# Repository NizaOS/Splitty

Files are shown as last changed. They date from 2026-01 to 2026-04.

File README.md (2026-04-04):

<header style="text-align: center; margin-bottom: 40px;">
<h1 style="font-size: 3em; margin-bottom: 10px;">SPLITTY</h1>
<p style="font-size: 1.2em; color: #555;">A 40% Wireless Split Mechanical Keyboard</p>
<p><b>Low Profile &bull; Choc v1 &bull; ZMK Firmware &bull; 1000mAh Battery Life</b></p>
<hr>
</header>
<section>
<h2>Project Overview</h2>
<p>SPLITTY is a custom-built, wireless split keyboard designed for portability and ergonomics. It utilizes the <b>Seeed Studio XIAO nRF52840</b> for Bluetooth 5.0 connectivity and is built on a custom PCB optimized for <b>Kailh Choc v1</b> low-profile switches.</p>


<h3>why i made this project</h3>
    <p>i wanted a low profile split keyboard that was actually portable and didnt cost a fortune. most commerical options are too bulky or wired only so i decided to desin something that fits in a laptop bag easily while keeping the ergonomics of a split layout.</p>

<h3>how to use</h3>
    <p>to use the keyboard you need to flash zmk firmware to both halves. double tap reset button on the xiao to enter bootloader mode then drag and drop the uf2 files. once its flashed you can pair it to your computer via bluetooth settings by searching for splitty. the left side is usually the central half that connects to the pc.</p>
    <h3>Technical Specifications</h3>
    <ul>
        <li><b>Microcontroller:</b> 2x Seeed Studio XIAO nRF52840 (Bluetooth 5.0)</li>
        <li><b>Switch Type:</b> Kailh Choc v1 (PG1350) - Linear/Tactile/Clicky</li>
        <li><b>Battery:</b> 2x 1000mAh LiPo (WLY394058) - Approx. 1+ month battery life</li>
        <li><b>PCB Features:</b> Hotswap support, reversible footprint, 1.2mm thickness</li>
        <li><b>Firmware:</b> ZMK (Wireless-first firmware)</li>
    </ul>
</section>
<hr>
<section>
    <h2>Bill of Materials (BOM)</h2>
    <p><i>Prices estimated in USD based on INR conversion ($1 &#8776; &#8377;90.27).</i></p>
            <table border="1" cellpadding="10" cellspacing="0" style="width: 100%; border-collapse: collapse; text-align: left;">
        <thead>
            <tr style="background-color: #f2f2f2;">
                <th>Component</th>
                <th>Qty</th>
                <th>Unit Price</th>
                <th>Total (USD)</th>
                <th>Sourcing Link</th>
            </tr>
        </thead>
        <tbody>
            <tr>
                <td><b>Seeed XIAO BLE nRF52840</b></td>
                <td>2</td>
                <td>$14.88</td>
                <td>$25.87</td>
                <td><a href="[https://www.fabtolab.com/seeed-xiao-ble-nrf52840-supports-arduino-micropython-bluetooth5.0-onboard-antenna-microcontroller-32-bit-arm-cortex-m4](https://www.fabtolab.com/seeed-xiao-ble-nrf52840-supports-arduino-micropython-bluetooth5.0-onboard-antenna-microcontroller-32-bit-arm-cortex-m4)" target="_blank">Fab.to.Lab</a></td>
            </tr>
            <tr>
                <td><b>Kailh Choc v1 Switches</b></td>
                <td>40</td>
                <td>$0.55</td>
                <td>$22.00</td>
                <td><a href="[https://neomacro.in/products/kailh-choc-pg1350-hot-swap-sockets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](https://neomacro.in/products/kailh-choc-pg1350-hot-swap-sockets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)" target="_blank">NeoMacro</a></td>
            </tr>
            <tr>
                <td><b>Choc Hotswap Sockets</b></td>
                <td>40</td>
                <td>$0.18</td>
                <td>$7.00</td>
                <td><a href="[https://neomacro.in/products/kailh-choc-v1-switches](https://neomacro.in/products/kailh-choc-v1-switches)" target="_blank">NeoMacro</a></td>
            </tr>
            <tr>
                <td><b>MBK/MCC Keycaps</b></td>
                <td>40</td>
                <td>$0.40</td>
                <td>$16.00</td>
                <td><a href="[https://neomacro.in/products/chocfox-cfx-choc-blank-keycaps?variant=49467027685654](https://neomacro.in/products/chocfox-cfx-choc-blank-keycaps?variant=49467027685654)" target="_blank">NeoMacro</a></td>
            </tr>
            <tr>
                <td><b>PCB (Manufacturing)</b></td>
                <td>1</td>
                <td>$21.00</td>
                <td>$21.00</td>
                <td><a href="[https://jlcpcb.com/](https://jlcpcb.com/)" target="_blank">JLCPCB</a></td>
            </tr>
            <tr>
                <td><b>3D Printed Case (Shipping)</b></td>
                <td>1</td>
                <td>$10.00</td>
                <td>$10.00</td>
                <td>Printing Legion</td>
            </tr>
            <tr>
                <td><b>LiPo Battery (1000mAh)</b><br><small>Model: WLY394058 (3.9mm thick)</small></td>
                <td>2</td>
                <td>$4.18</td>
                <td>$8.36</td>
                <td><a href="[https://robu.in/product/wly394058-1000mah-3-7v-single-cell-rechargeable-lipo-battery/](https://robu.in/product/wly394058-1000mah-3-7v-single-cell-rechargeable-lipo-battery/)" target="_blank">Robu.in</a></td>
            </tr>
            <tr>
                <td><b>1N4148W Diodes (SOD-123)</b></td>
                <td>40</td>
                <td>$0.006</td>
                <td>$0.24</td>
                <td><a href="[https://robu.in/product/1n4148w-sod-123-1206-diodereel-of-3000/](https://robu.in/product/1n4148w-sod-123-1206-diodereel-of-3000/)" target="_blank">Robu.in</a></td>
            </tr>
            <tr>
                <td><b>806K1 Resistor (0805)</b></td>
                <td>10</td>
                <td>$0.023</td>
                <td>$0.14</td>
                <td><a href="[https://robu.in/product/ac0402fr-07806kl-yageo-62-5mw-thick-film-resistors-50v-](https://robu.in/product/ac0402fr-07806kl-yageo-62-5mw-thick-film-resistors-50v-)±100ppm-℃-±1-806kω-0402-chip-resistor-surface-mount-rohs/" target="_blank">Robu.in</a></td>
            </tr>
            <tr>
                <td><b>2M1 Resistor (0805)</b></td>
                <td>10</td>
                <td>$0.020</td>
                <td>$0.11</td>
                <td><a href="[https://robu.in/product/rc0603fr-0716rl-yageo-smd-chip-resistor-16-ohm-](https://robu.in/product/rc0603fr-0716rl-yageo-smd-chip-resistor-16-ohm-)±-1-100-mw-0603-1608-metric-thick-film-general-purpose/" target="_blank">Robu.in</a></td>
            </tr>
            <tr style="font-weight: bold; background-color: #e6e6e6;">
                <td colspan="3" style="text-align: right;">ESTIMATED TOTAL</td>
                <td colspan="2">$110.72</td>
            </tr>
        </tbody>
    </table>
</section>

<hr>

<div id="gallery" style="padding: 20px; background-color: #f9f9f9; border: 1px solid #ddd; margin-top: 30px;">
    <h2 style="text-align: center;">Project Gallery</h2>
    
  

  



</div>
</div>

</body>
</html>

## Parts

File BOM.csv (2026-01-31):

Item | Quantity | Unit Price | Total Price | Source | Link
Seeed XIAO BLE nRF52840 | 2 | $14.88 | $25.87 | Fab.to.Lab | https://www.fabtolab.com/seeed-xiao-ble-nrf52840-supports-arduino-micropython-bluetooth5.0-onboard-antenna-microcontroller-32-bit-arm-cortex-m4
Kailh Choc v1 Switches | 40 | $0.55 | $22.00 | NeoMacro | https://neomacro.in/products/kailh-choc-pg1350-hot-swap-sockets
Choc Hotswap Sockets | 40 | $0.18 | $7.00 | NeoMacro | https://neomacro.in/products/kailh-choc-v1-switches
MBK/MCC Keycaps | 40 | $0.40 | $16.00 | NeoMacro | https://neomacro.in/products/chocfox-cfx-choc-blank-keycaps?variant=49467027685654
PCB (Manufacturing) | 1 | $21.00 | $21.00 | JLCPCB | https://jlcpcb.com/
3D Printed Case (Shipping) | 1 | $10.00 | $10.00 | Printing Legion | N/A
LiPo Battery (1000mAh) | 2 | $4.18 | $8.36 | Robu.in | https://robu.in/product/wly394058-1000mah-3-7v-single-cell-rechargeable-lipo-battery/
1N4148W Diodes (SOD-123) | 40 | $0.006 | $0.24 | Robu.in | https://robu.in/product/1n4148w-sod-123-1206-diodereel-of-3000/
806K1 Resistor (0805) | 10 | $0.023 | $0.14 | Robu.in | https://robu.in/product/ac0402fr-07806kl-yageo-62-5mw-thick-film-resistors-50v-±100ppm-℃-±1-806kω-0402-chip-resistor-surface-mount-rohs/
2M1 Resistor (0805) | 10 | $0.020 | $0.11 | Robu.in | https://robu.in/product/rc0603fr-0716rl-yageo-smd-chip-resistor-16-ohm-±-1-100-mw-0603-1608-metric-thick-film-general-purpose/
TOTAL |  |  | $110.72

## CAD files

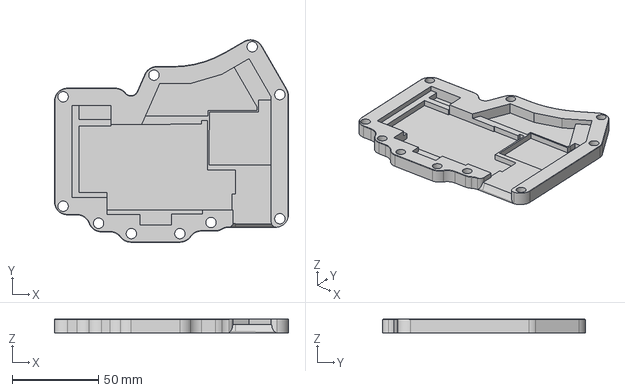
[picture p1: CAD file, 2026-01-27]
SplittyCAD/Right FInal.step
135.4 x 117.2 x 8.04 mm

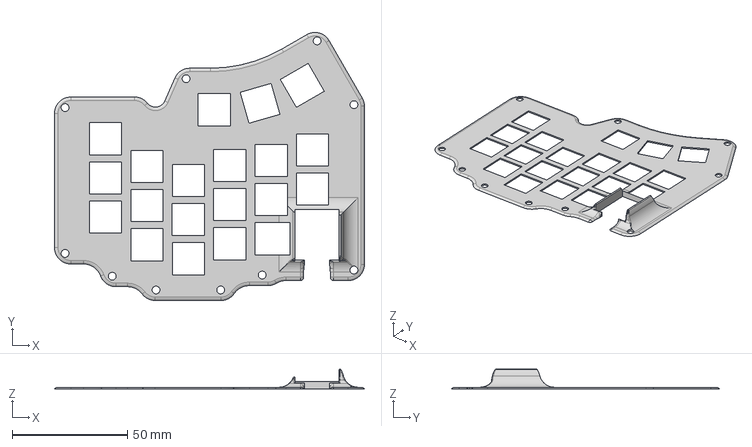
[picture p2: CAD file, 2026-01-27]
SplittyCAD/Upper Right Final.step
134.5 x 116.3 x 8.59 mm

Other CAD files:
SplittyCAD/Left FInal.step
SplittyCAD/Upper Left Final.step
SplittyCAD/Left FInal.stl
SplittyCAD/Right FInal.stl
SplittyCAD/Upper Left Final.stl
SplittyCAD/Upper Right Final.stl

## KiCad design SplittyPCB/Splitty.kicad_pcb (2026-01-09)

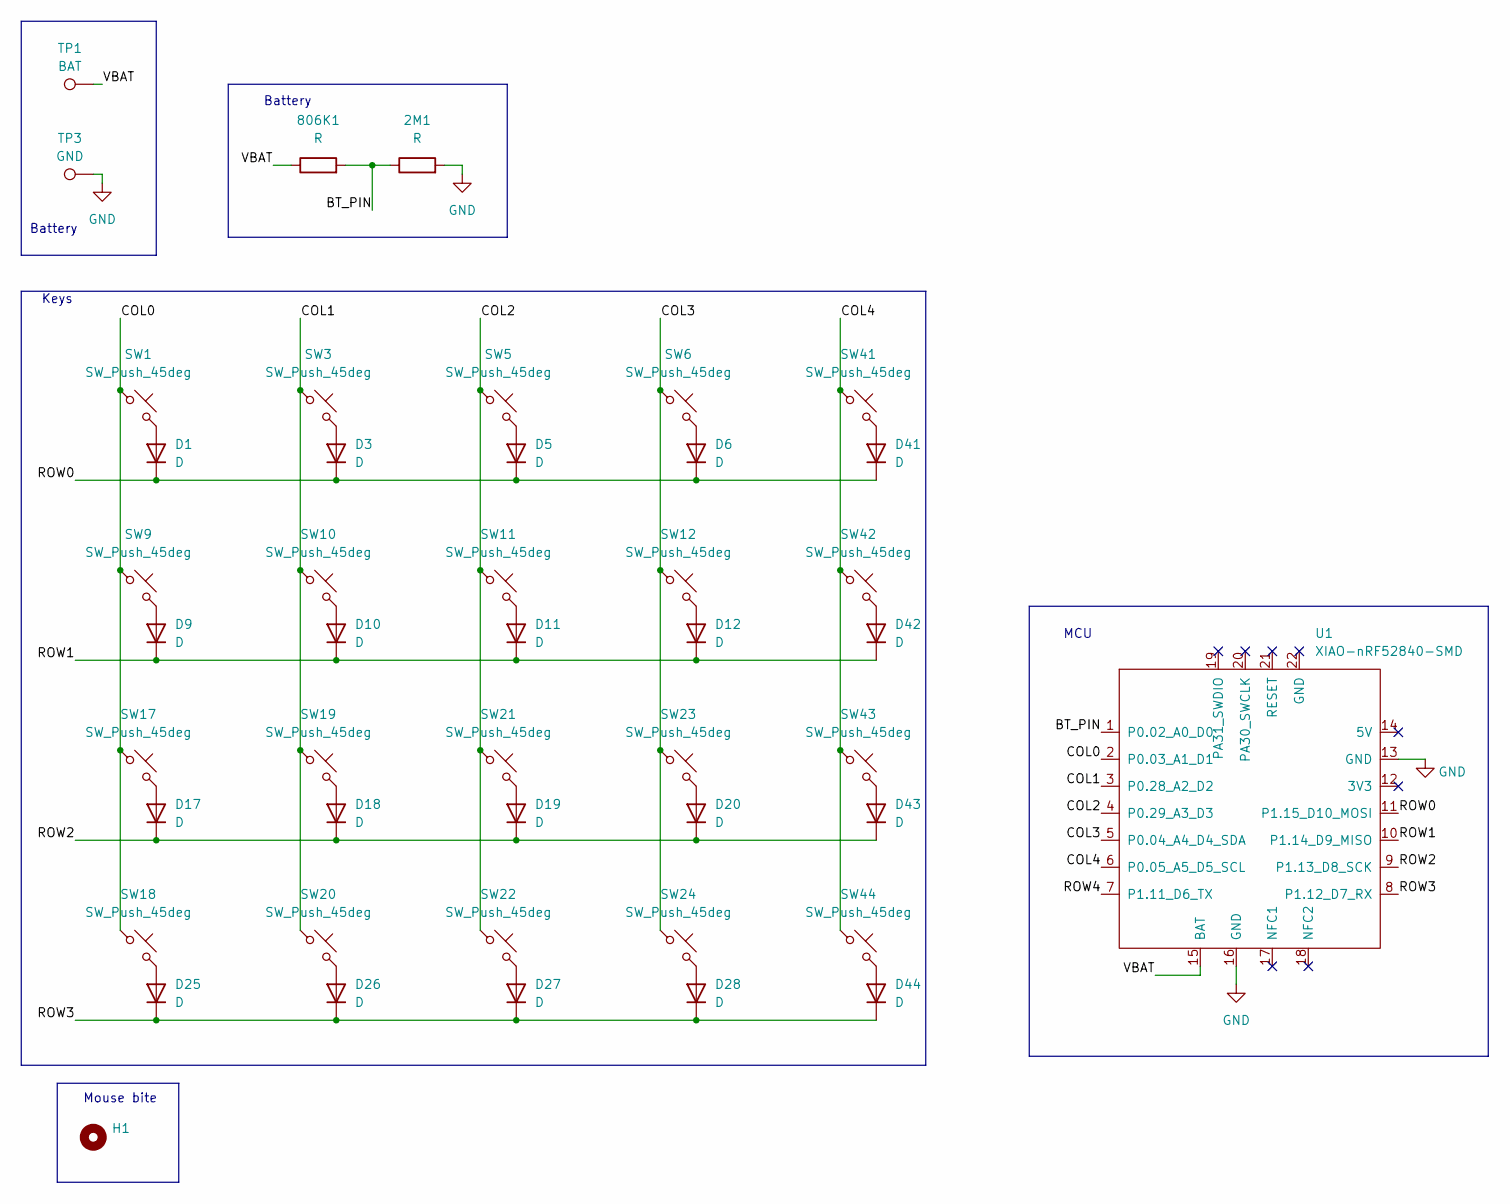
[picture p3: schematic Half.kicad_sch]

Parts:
2M1, 806K1: R; R_0805_2012Metric
D1, D3, D5, D6, D9, D10, D11, D12, D17, D18, D19, D20, D25, D26, D27, D28, D41, D42, D43, D44: D; D_SOD-123
H1: MountingHole; mouse-bite-2mm-slot
SW1, SW3, SW5, SW6, SW9, SW10, SW11, SW12, SW17, SW18, SW19, SW20, SW21, SW22, SW23, SW24, SW41, SW42, SW43, SW44: SW_Push_45deg; SW_choc_v1_HS_CPG135001S30_1u
TP1: BAT; TestPoint_Pad_D2.0mm
TP3: GND; TestPoint_Pad_D2.0mm
U1: XIAO-nRF52840-SMD; modified-XIAO-nRF52840-SMD

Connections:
/Left/BT_PIN: 2M1.1, 806K1.2, U1.1 (P0.02_A0_D0)
/Left/COL0: SW1.1, SW9.1, SW17.1, SW18.1, U1.2 (P0.03_A1_D1)
/Left/COL1: SW3.1, SW10.1, SW19.1, SW20.1, U1.3 (P0.28_A2_D2)
/Left/COL2: SW5.1, SW11.1, SW21.1, SW22.1, U1.4 (P0.29_A3_D3)
/Left/COL3: SW6.1, SW12.1, SW23.1, SW24.1, U1.5 (P0.04_A4_D4_SDA)
/Left/COL4: SW41.1, SW42.1, SW43.1, SW44.1, U1.6 (P0.05_A5_D5_SCL)
/Left/ROW0: D1.1 (K), D3.1 (K), D5.1 (K), D6.1 (K), D41.1 (K), U1.11 (P1.15_D10_MOSI)
/Left/ROW1: D9.1 (K), D10.1 (K), D11.1 (K), D12.1 (K), D42.1 (K), U1.10 (P1.14_D9_MISO)
/Left/ROW2: D17.1 (K), D18.1 (K), D19.1 (K), D20.1 (K), D43.1 (K), U1.9 (P1.13_D8_SCK)
/Left/ROW3: D25.1 (K), D26.1 (K), D27.1 (K), D28.1 (K), D44.1 (K), U1.8 (P1.12_D7_RX)
/Left/ROW4: U1.7 (P1.11_D6_TX)
/Left/VBAT: 806K1.1, TP1.1, U1.15 (BAT)
GND: 2M1.2, TP3.1, U1.13 (GND), U1.16 (GND); also elsewhere on the board
unnamed: D1.2 (A), SW1.2
unnamed: D3.2 (A), SW3.2
unnamed: D5.2 (A), SW5.2
unnamed: D6.2 (A), SW6.2
unnamed: D9.2 (A), SW9.2
unnamed: D10.2 (A), SW10.2
unnamed: D11.2 (A), SW11.2
unnamed: D12.2 (A), SW12.2
unnamed: D17.2 (A), SW17.2
unnamed: D18.2 (A), SW19.2
unnamed: D19.2 (A), SW21.2
unnamed: D20.2 (A), SW23.2
unnamed: D25.2 (A), SW18.2
unnamed: D26.2 (A), SW20.2
unnamed: D27.2 (A), SW22.2
unnamed: D28.2 (A), SW24.2
unnamed: D41.2 (A), SW41.2
unnamed: D42.2 (A), SW42.2
unnamed: D43.2 (A), SW43.2
unnamed: D44.2 (A), SW44.2

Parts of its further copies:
D2, D4, D7, D8, D13, D14, D15, D16, D21, D22, D23, D24, D29, D30, D31, D32, D46, D47, D48, D49: D; D_SOD-123
R2, R4: R; R_0805_2012Metric
SW2, SW4, SW7, SW8, SW13, SW14, SW15, SW16, SW25, SW26, SW27, SW28, SW29, SW30, SW31, SW32, SW46, SW47, SW48, SW49: SW_Push_45deg; SW_choc_v1_HS_CPG135001S30_1u
TP2: BAT; TestPoint_Pad_D2.0mm
TP4: GND; TestPoint_Pad_D2.0mm
U2: XIAO-nRF52840-SMD; modified-XIAO-nRF52840-SMD

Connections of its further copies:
/Right/BT_PIN: R2.2, R4.1, U2.1 (P0.02_A0_D0)
/Right/COL0: SW2.1, SW13.1, SW25.1, SW26.1, U2.2 (P0.03_A1_D1)
/Right/COL1: SW4.1, SW14.1, SW27.1, SW28.1, U2.3 (P0.28_A2_D2)
/Right/COL2: SW7.1, SW15.1, SW29.1, SW30.1, U2.4 (P0.29_A3_D3)
/Right/COL3: SW8.1, SW16.1, SW31.1, SW32.1, U2.5 (P0.04_A4_D4_SDA)
/Right/COL4: SW46.1, SW47.1, SW48.1, SW49.1, U2.6 (P0.05_A5_D5_SCL)
/Right/ROW0: D2.1 (K), D4.1 (K), D7.1 (K), D8.1 (K), D46.1 (K), U2.11 (P1.15_D10_MOSI)
/Right/ROW1: D13.1 (K), D14.1 (K), D15.1 (K), D16.1 (K), D47.1 (K), U2.10 (P1.14_D9_MISO)
/Right/ROW2: D21.1 (K), D22.1 (K), D23.1 (K), D24.1 (K), D48.1 (K), U2.9 (P1.13_D8_SCK)
/Right/ROW3: D29.1 (K), D30.1 (K), D31.1 (K), D32.1 (K), D49.1 (K), U2.8 (P1.12_D7_RX)
/Right/ROW4: U2.7 (P1.11_D6_TX)
/Right/VBAT: R2.1, TP2.1, U2.15 (BAT)
GND: R4.2, TP4.1, U2.13 (GND), U2.16 (GND); also elsewhere on the board
unnamed: D2.2 (A), SW2.2
unnamed: D4.2 (A), SW4.2
unnamed: D7.2 (A), SW7.2
unnamed: D8.2 (A), SW8.2
unnamed: D13.2 (A), SW13.2
unnamed: D14.2 (A), SW14.2
unnamed: D15.2 (A), SW15.2
unnamed: D16.2 (A), SW16.2
unnamed: D21.2 (A), SW25.2
unnamed: D22.2 (A), SW27.2
unnamed: D23.2 (A), SW29.2
unnamed: D24.2 (A), SW31.2
unnamed: D29.2 (A), SW26.2
unnamed: D30.2 (A), SW28.2
unnamed: D31.2 (A), SW30.2
unnamed: D32.2 (A), SW32.2
unnamed: D46.2 (A), SW46.2
unnamed: D47.2 (A), SW47.2
unnamed: D48.2 (A), SW48.2
unnamed: D49.2 (A), SW49.2

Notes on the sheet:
Keys
Battery
Mouse bite
Battery
MCU

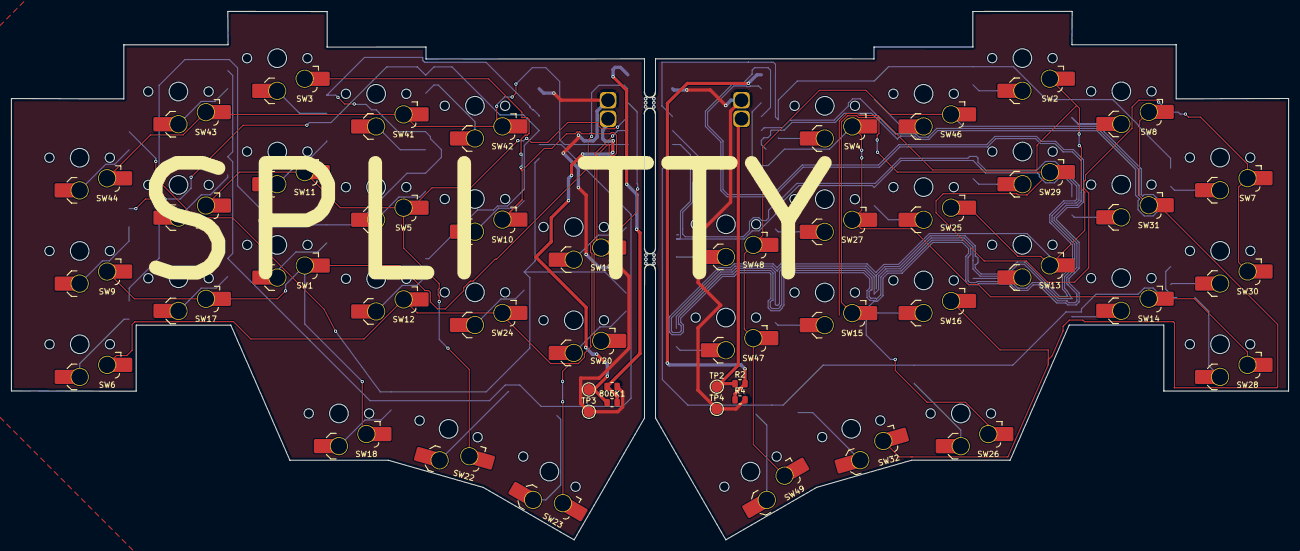
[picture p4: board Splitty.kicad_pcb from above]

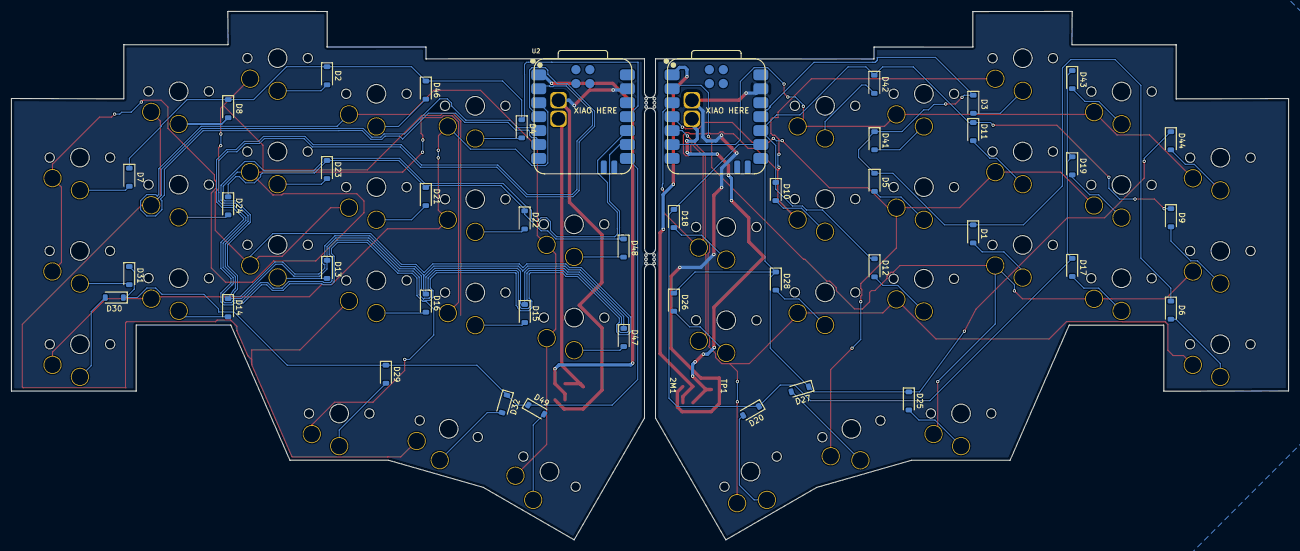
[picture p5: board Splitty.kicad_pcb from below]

Board: 2 copper layers, 232.7 x 96.3 mm, 92 parts (42 on the bottom side), 63 nets.

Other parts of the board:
H2, H4: break off; mouse-bite-2mm-slot

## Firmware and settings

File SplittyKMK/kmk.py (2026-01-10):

import board
from kmk.kmk_keyboard import KMKKeyboard
from kmk.keys import KC
from kmk.scanners import DiodeOrientation
from kmk.modules.split import Split, SplitType
from kmk.modules.layers import Layers
from kmk.modules.power import Power
from kmk.modules.vbat import Vbat

keyboard = KMKKeyboard()

keyboard.col_pins = (board.D0, board.D1, board.D2, board.D3, board.D4)
keyboard.row_pins = (board.D10, board.D9, board.D8, board.D7)
keyboard.diode_orientation = DiodeOrientation.COL2ROW

layers = Layers()
power = Power()

vbat = Vbat(
    pin=board.A0,
    divider=2.48,
    voltage_max=4.2,
    voltage_min=3.5
)

split = Split(
    split_type=SplitType.BLE,
    use_data_pin_for_side=False,
    split_side=None,
)

keyboard.modules = [layers, power, vbat, split]

keyboard.keymap = [
    [
        KC.Q,    KC.W,    KC.E,    KC.R,    KC.T,      KC.Y,    KC.U,    KC.I,    KC.O,    KC.P,
        KC.A,    KC.S,    KC.D,    KC.F,    KC.G,      KC.H,    KC.J,    KC.K,    KC.L,    KC.SCLN,
        KC.Z,    KC.X,    KC.C,    KC.V,    KC.B,      KC.N,    KC.M,    KC.COMMA,KC.DOT,  KC.SLSH,
        KC.LCTL, KC.LALT, KC.LGUI, KC.LSFT, KC.SPC,    KC.ENT,  KC.BSPC, KC.TAB,  KC.RSFT, KC.MO(1),
    ],
    [
        KC.N1,   KC.N2,   KC.N3,   KC.N4,   KC.N5,     KC.N6,   KC.N7,   KC.N8,   KC.N9,   KC.N0,
        KC.F1,   KC.F2,   KC.F3,   KC.F4,   KC.F5,     KC.LEFT, KC.DOWN, KC.UP,   KC.RGHT, KC.QUOT,
        KC.TRNS, KC.TRNS, KC.TRNS, KC.TRNS, KC.TRNS,   KC.TRNS, KC.TRNS, KC.BAT,  KC.TRNS, KC.TRNS,
        KC.TRNS, KC.TRNS, KC.TRNS, KC.TRNS, KC.TRNS,   KC.TRNS, KC.DEL,  KC.TRNS, KC.TRNS, KC.TRNS,
    ]
]

if __name__ == '__main__':
    keyboard.go()

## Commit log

2026-01-09 Added PCB designs
    [Half.kicad_sch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]
2026-01-09 Added CAD files
    [Left.step, Right.step, Upper Left.step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]
2026-01-20 added cad model with all components included and unified parts
2026-01-31 Added BOM file
    [SBOM.csv]
